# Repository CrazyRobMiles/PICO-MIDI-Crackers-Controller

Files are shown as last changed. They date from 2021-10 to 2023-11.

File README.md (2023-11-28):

## PICO MIDI Crackers Controller
Designs and software for a MIDI controller described in HackSpace magazine. 

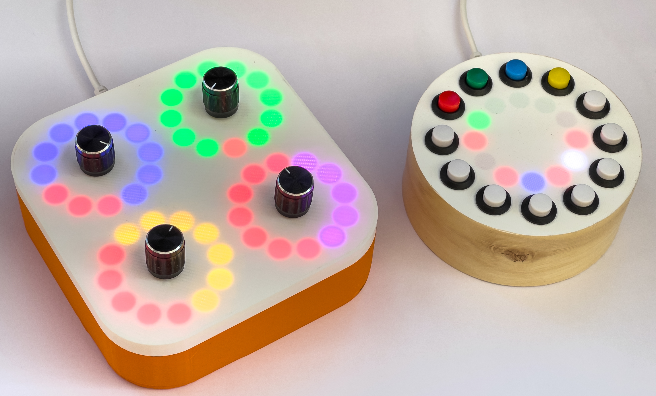
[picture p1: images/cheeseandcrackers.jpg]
Cheesebox device with a box of cheese


The PICO MIDI Crackers controller uses four rotary inputs and four pixel rings to create a programmable MIDI controller. It is programmed in Circuit Python.
## Video
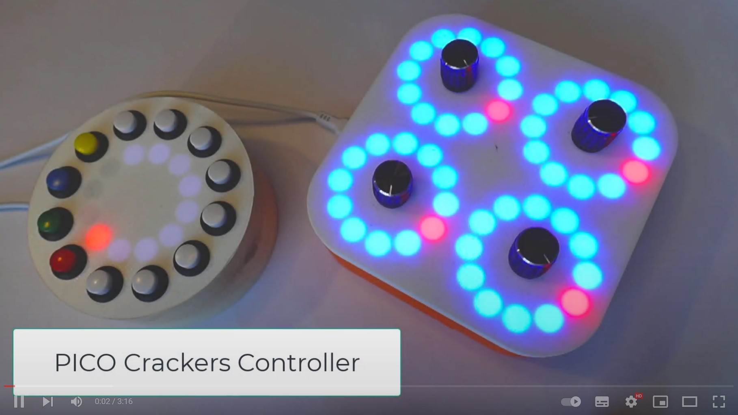
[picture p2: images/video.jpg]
YouTube Screenshot (https://youtu.be/vI_cmTigS_Q)


To find out more about the device click on the image above to see a short video.
You can find the program in the code folder. 
## Construction
The software is written in Circuit Python which version 7.0 can be installed on your Raspberry PI PICO using the image from here: https://circuitpython.org/downloads. It uses the Adafruit adafruit_bus_device and adafruit_midi libraries which need to be copied into the lib folder on the Circuit Python drive of your PICO. You can find these here: https://circuitpython.org/libraries. 
### Connections
Check the code for the GPIO connections for the rotary encoder. You can see it below, it starts on line 213 in the main.py file.
```
self.controllers = [
    MidiController(client=self, name="c1", encoder_pin1=board.GP8, encoder_pin2=board.GP9, pulses_rev=20,
                   button_pin=board.GP14, pixel_start=24, no_of_pixels=12, forward=True, pixel_offset=2,
                   configs=c1),
    MidiController(client=self, name="c2", encoder_pin1=board.GP10, encoder_pin2=board.GP11, pulses_rev=20,
                   button_pin=board.GP15, pixel_start=36, no_of_pixels=12, forward=True, pixel_offset=-1,
                   configs=c2),
    MidiController(client=self, name="c3", encoder_pin1=board.GP6, encoder_pin2=board.GP7, pulses_rev=20,
                   button_pin=board.GP17, pixel_start=12, no_of_pixels=12, forward=True, pixel_offset=5,
                   configs=c3),
    MidiController(client=self, name ="c4", encoder_pin1=board.GP4, encoder_pin2=board.GP5, pulses_rev=20,
                   button_pin=board.GP12, pixel_start=0, no_of_pixels=12, forward=False, pixel_offset=8,
                   configs=c4)
    ]
```
You can change the GPIO values to match your hardware configuration.
## MIDI
The controller outputs control changed messages on MIDI channel 1. The control numbers used start at 21. An updated value is sent each time a control is moved. There are four sets of control settings, blue, yellow, green and magenta. Toggle between the settings by pressing down the knob of any controller. 

- blue controls 21,22,23,24
- yellow controls 25,26,27,28
- green controls 29,30,31,32
- magenta controls 33,34,35,36

## Pure Data
The patches folder contains the Pure Data patches and resources for the synthesizer. Open the "CheeseSynth" patch with Pure Data.
# Devices
You can use the controller with lots of devices....
## Synthstrom Deluge
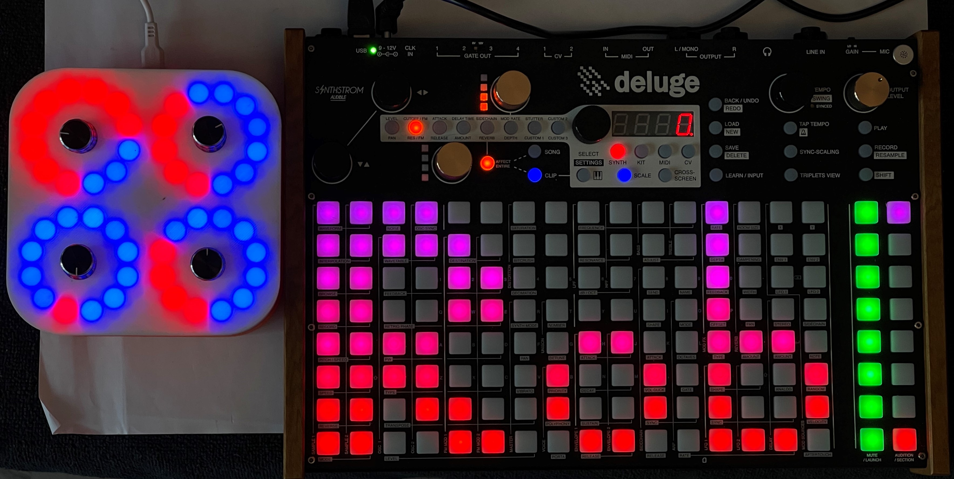
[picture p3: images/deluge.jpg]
Crackers controller with Synthstrom Deluge

The [Synthstrom Deluge](https://synthstrom.com/product/deluge/) is an awesome synthesizer, sampler and sequencer. 

You can connect the Crackers Controller directly to a Deluge. You'll need a "Type A Female to USB B Male Scanner Printer Extension Adapter Cable" that will let you plug the USB cable from the controller into the Deluge. You will also have to make sure that the Deluge is powered from a mains adapter. 

You use the MIDI learn feature of the Deluge to assign controller outputs to setting values:

* Go to the MIDI, Synth or sample clip that you want to use with the controller.
* Find a setting for the clip that you want to control. I like playing with the value of Bitcrush (7 from the left and 1 down).
* Hold down the SHIFT key and press the setting button (perhaps Bitcrush) you want to control.  This should make the setting button flash and the current value of the setting is shown in the four digit display. You can now change that settign by twiddling the black select knob in the middle of the Deluge.
* To assign one of the controller knobs to this setting press and hold the Learn button. and twiddle the knob on the Crackers Controller. The four digit display will show "LEAr" to indicate that the control has been learned.
* Now when you twiddle the knob on the Crackers Controller you should see the value in the display changing. 
* The controller assignments are saved as part of the song data so they will be restored when you reload the song. 

Some settings can't be controlled over MIDI. If you try to control one of these you will see the word "Cant" displayed when you press the Learn button.

Remember that you have four different banks of setting values, change between the banks by pressing in any of the knobs on the controller. If you want to control a particular setting from multiple banks you can do this by using learn multiple times for that setting.

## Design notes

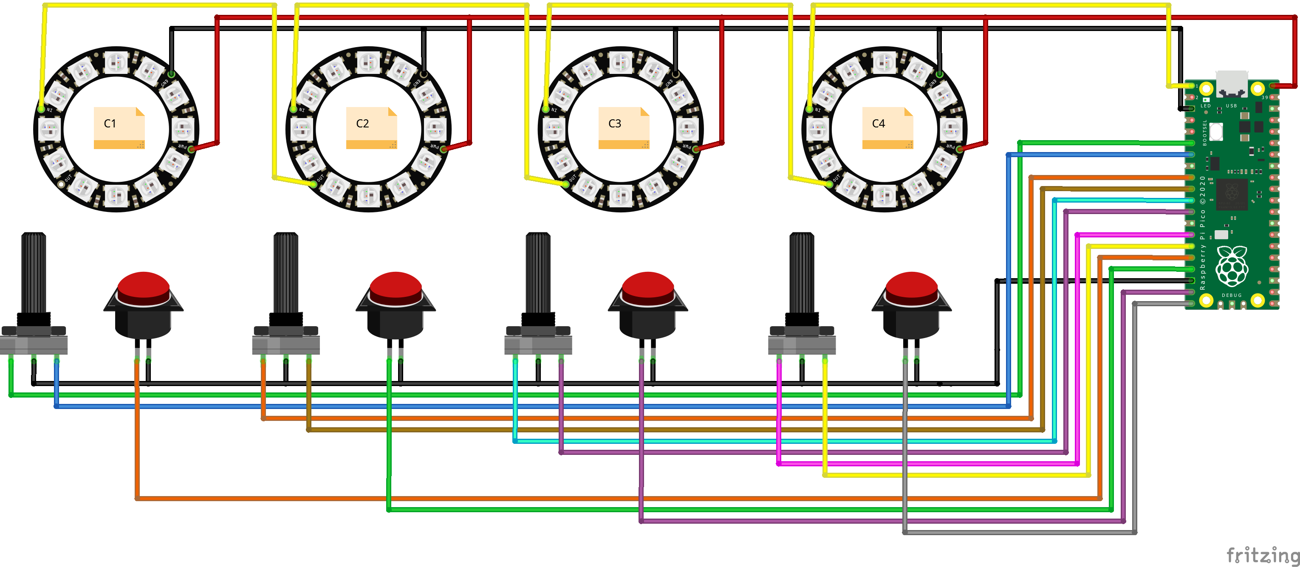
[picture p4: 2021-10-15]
circuit/Circuit Diagram.png

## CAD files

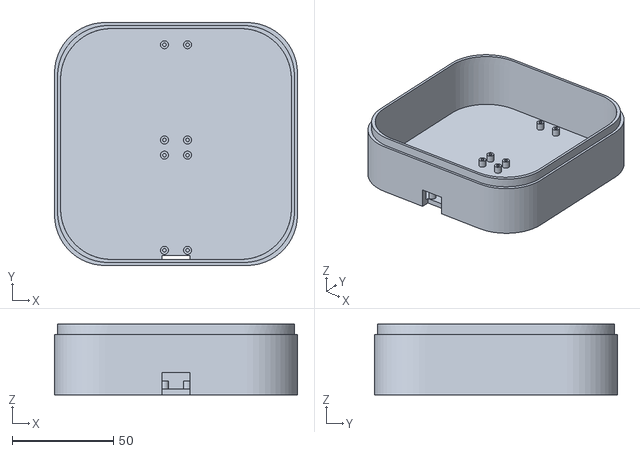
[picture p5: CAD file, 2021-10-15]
case/caseBottom.stl
120.0 x 120.0 x 35.0

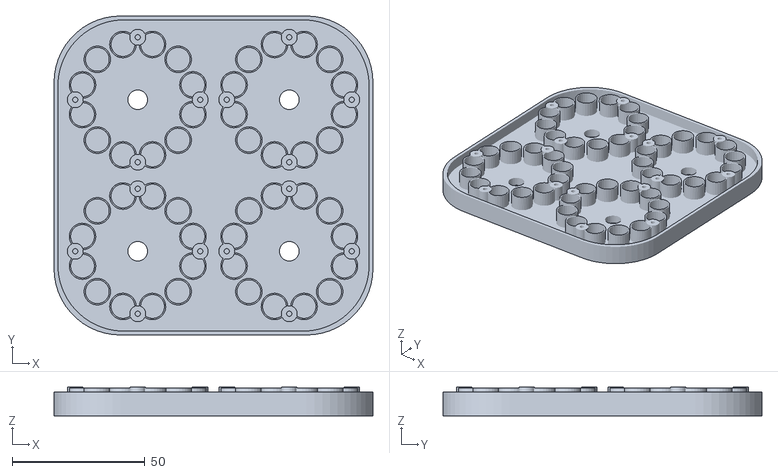
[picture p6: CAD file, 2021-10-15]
case/caseTop.stl
120.0 x 120.0 x 10.8

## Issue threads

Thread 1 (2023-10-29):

Code issues

viragored, 2023-10-29:
I've finally assembled one of these - the hardware all checked out with my test code but the software didn't work. The code doesn't match the GPIO wiring in Hackspace #49. These fixes made it work for me - as far as I can tell.
In class CrackersController:
    self.controllers = [
        # Button GP pins should be 1=12; 2=13; 3=14; 4=15 [Not 14,15,17,12]
        # encoder_pins should be 4,5; 6,7; 8,9; 10,11 [Not 1=8,9; 2=10,11; 3=6,7; 4=4,5] - at least on my physical build
        # pixel_start should be 1=36; 2=24
        # alter "forward" to suit the user's actual wiring

In class Controller():
    def button_down(self):
The logic appears to be reversed, so all neopixels change colour when one button is pressed, and not just the encoder that is pressed
Change the next line to:
        if **not** self.client.change_all_controllers:

CrazyRobMiles, 2023-11-28:
Hi. Sorry to hear you had problems getting it to work. The pins thing is a problem. I think the circuit diagram is not very helpful as it doesn't have explicit pin assignments. I'll add a paragraph to the help telling folks they can build it how they like and then point then them at the code to change.

The change all thing was an idea that I wanted to have them all change at once so I could have "pages" of settings. The idea was that you make change_all_controllers false if you want that behaviour. I was going to add a behaviour (for example press all the buttons at once) to toggle the setting but never got round to it.

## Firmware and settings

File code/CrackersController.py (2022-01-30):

import board

import time
import gc
import board
import neopixel
import rotaryio
from digitalio import DigitalInOut, Direction, Pull
import usb_midi
import adafruit_midi
from adafruit_midi.note_on import NoteOn
from adafruit_midi.note_off import NoteOff
from adafruit_midi.control_change import ControlChange
from adafruit_debouncer import Debouncer

class Col:
    
    RED = (255, 0, 0)
    YELLOW = (255, 150, 0)
    GREEN = (0, 255, 0)
    CYAN = (0, 255, 255)
    BLUE = (0, 0, 255)
    MAGENTA = (255, 0, 255)
    WHITE = (255, 255, 255)
    BLACK = (0, 0, 0)
    GREY = (10, 10, 10)
    VIOLET = (127,0,155)
    INDIGO = (75,0,130)
    ORANGE = (255,165,0)
       
    values=(RED, GREEN, BLUE, YELLOW, MAGENTA, CYAN, GREY, WHITE)
    
   
    @staticmethod
    def dim(col):
        return (col[0]/40, col[1]/40, col[2]/40)

class ControllerConfig():
    
    def __init__(self, min_val=0, max_val=127,turns=1.0,init_value=0,
                 controller_value = 0, background_col = Col.BLUE,
                 val_col = Col.RED):
        self.min_val = min_val
        self.max_val = max_val
        self.turns = turns
        self.encoder_value = 0
        self.init_value = init_value
        self.controller_value = init_value
        self.val_col = val_col
        self.background_col = background_col
        
class MidiControllerConfig(ControllerConfig):
    
    def __init__(self, min_val=0, max_val=127,turns=1.0,init_value=0,
                 controller_value = 0, background_col = Col.BLUE,
                 val_col = Col.RED, midi_channel=0,midi_control=1):
        super(MidiControllerConfig,self).__init__(
            min_val, max_val,turns,init_value,
                 controller_value, background_col,
                 val_col)
        self.midi_channel=midi_channel
        self.midi_control = midi_control

class Controller():
    def __init__(self, client, name, encoder_pin1, encoder_pin2, pulses_rev,
                 button_pin, pixel_start, no_of_pixels, pixel_offset, forward,
                 configs
                 ):
        self.name = name
        self.client =  client
        self.encoder= rotaryio.IncrementalEncoder(encoder_pin1, encoder_pin2)
        self.pulses_rev = pulses_rev
        self.last_encoder_position = 0
        tmp_pin = DigitalInOut(button_pin)
        tmp_pin.pull = Pull.UP
        self.button_debounce = Debouncer(tmp_pin,interval=0.01)
        self.pixel_start = pixel_start
        self.no_of_pixels = no_of_pixels
        self.pixel_offset = pixel_offset
        self.forward = forward
        self.first_run = True
        self.configs = configs
        self.active_config_no = 0
        self.active_config = configs[0]
    
    def set_range(self,min_val,max_val,turns,pulses_rev):
        self.min = min_val
        self.max = max_val
        self.turns = turns
        self.pulses_rev = pulses_ref
        
    def draw_cursor(self):
        pixels = self.no_of_pixels
        base = self.pixel_start
        offset = self.pixel_offset
        pulse_limit = int(self.pulses_rev * self.active_config.turns)-1
        turn_amount = self.active_config.encoder_value / pulse_limit
        cursor = int(pixels*turn_amount)
        pos=0
        while pos < pixels:
            pix = base + ((pos+offset) % pixels)
            if pos<=cursor:
                self.client.pixels[pix] = self.active_config.val_col
            else:
                self.client.pixels[pix] = self.active_config.background_col
            pos = pos + 1
                    
    def update_encoder(self):
        new_encoder_position = self.encoder.position
        encoder_change = self.last_encoder_position - new_encoder_position
        
        if encoder_change != 0 or self.first_run:
            if self.forward:
                new_pos = self.active_config.encoder_value - encoder_change
            else:
                new_pos = self.active_config.encoder_value + encoder_change
                
            if new_pos<0:
                new_pos=0
                
            pulse_limit = int(self.pulses_rev * self.active_config.turns)-1
            
            if new_pos>=pulse_limit:
                new_pos=pulse_limit
                 
            if self.active_config.encoder_value != new_pos or self.first_run:
                self.first_run = False
                self.active_config.encoder_value = new_pos
                turn_amount = new_pos / pulse_limit
                val_range = self.active_config.max_val - self.active_config.min_val
                scaled_change = turn_amount * val_range
                self.active_config.controller_value=scaled_change
                self.draw_cursor()
                self.encoder_changed()
                
        self.last_encoder_position = new_encoder_position
        
    def update(self):
        self.button_debounce.update()
        if self.button_debounce.fell:
            self.button_down()
        if self.button_debounce.rose:
            self.button_up()
            
        self.update_encoder()

    def reset(self):
        self.count=0;
        
    def step_controller(self):
        self.active_config_no = (self.active_config_no + 1) % len(self.configs)
        self.active_config = self.configs[self.active_config_no]
        self.draw_cursor()
    
    def button_down(self):
        if self.client.change_all_controllers:
            for controller in self.client.controllers:
                controller.step_controller()
        else:
            self.step_controller()
        
    def button_up(self):
        pass


class MidiController(Controller):
    
    def __init__(self, client, name, encoder_pin1, encoder_pin2, pulses_rev,
                 button_pin, pixel_start, no_of_pixels, pixel_offset, forward,
                 configs):
        super(MidiController,self).__init__(client = client, name = name,
                 encoder_pin1 = encoder_pin1, encoder_pin2 = encoder_pin2,
                 pulses_rev = pulses_rev, button_pin = button_pin,
                 pixel_start = pixel_start, no_of_pixels = no_of_pixels,
                 forward = forward, pixel_offset = pixel_offset,
                 configs=configs)
    
    def encoder_changed(self):
        self.client.midi.send(ControlChange(self.active_config.midi_control,
            round(self.active_config.controller_value)), channel=self.active_config.midi_channel)

class CrackersController:

    def __init__(self):
        print("Rob Miles Crackers Midi Controller 1.0")
        base=20
        
        c1 = [
            MidiControllerConfig(midi_channel=0,midi_control=base+1),
            MidiControllerConfig(midi_channel=0,midi_control=base+5, background_col = Col.YELLOW),
            MidiControllerConfig(midi_channel=0,midi_control=base+9, background_col = Col.GREEN),
            MidiControllerConfig(midi_channel=0,midi_control=base+13, background_col = Col.MAGENTA)
            ]
        
        c2 = [
            MidiControllerConfig(midi_channel=0,midi_control=base+2),
            MidiControllerConfig(midi_channel=0,midi_control=base+6, background_col = Col.YELLOW),
            MidiControllerConfig(midi_channel=0,midi_control=base+10, background_col = Col.GREEN),
            MidiControllerConfig(midi_channel=0,midi_control=base+14, background_col = Col.MAGENTA)
            ]
        c3 = [
            MidiControllerConfig(midi_channel=0,midi_control=base+3),
            MidiControllerConfig(midi_channel=0,midi_control=base+7, background_col = Col.YELLOW),
            MidiControllerConfig(midi_channel=0,midi_control=base+11, background_col = Col.GREEN),
            MidiControllerConfig(midi_channel=0,midi_control=base+15, background_col = Col.MAGENTA)
            ]
        c4 = [
            MidiControllerConfig(midi_channel=0,midi_control=base+4),
            MidiControllerConfig(midi_channel=0,midi_control=base+8, background_col = Col.YELLOW),
            MidiControllerConfig(midi_channel=0,midi_control=base+12, background_col = Col.GREEN),
            MidiControllerConfig(midi_channel=0,midi_control=base+16, background_col = Col.MAGENTA)
            ]
        self.controllers = [
            MidiController(client=self, name="c1", encoder_pin1=board.GP8, encoder_pin2=board.GP9, pulses_rev=20,
                           button_pin=board.GP14, pixel_start=24, no_of_pixels=12, forward=True, pixel_offset=2,
                           configs=c1),
            MidiController(client=self, name="c2", encoder_pin1=board.GP10, encoder_pin2=board.GP11, pulses_rev=20,
                           button_pin=board.GP15, pixel_start=36, no_of_pixels=12, forward=True, pixel_offset=-1,
                           configs=c2),
            MidiController(client=self, name="c3", encoder_pin1=board.GP6, encoder_pin2=board.GP7, pulses_rev=20,
                           button_pin=board.GP17, pixel_start=12, no_of_pixels=12, forward=True, pixel_offset=5,
                           configs=c3),
            MidiController(client=self, name ="c4", encoder_pin1=board.GP4, encoder_pin2=board.GP5, pulses_rev=20,
                           button_pin=board.GP12, pixel_start=0, no_of_pixels=12, forward=False, pixel_offset=8,
                           configs=c4)
            ]
        self.midi = adafruit_midi.MIDI(midi_out=usb_midi.ports[1], out_channel=0)
        no_of_pixels = len(self.controllers)*12
        self.pixels = neopixel.NeoPixel(board.GP13,no_of_pixels,auto_write=False)
        self.pixels.brightness = 0.5
        self.change_all_controllers = True
        
    def button_down(self,controller):
        pass
        
    def button_up(self,controller):
        pass

    def encoder_changed(self, controller, change):
        pass

    def update(self):
        for controller in self.controllers:
            controller.update()
        self.pixels.show()


controller = CrackersController()
while True:
    controller.update()
